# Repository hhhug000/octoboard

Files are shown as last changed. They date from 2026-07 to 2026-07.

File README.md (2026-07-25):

# Octoboard

An ATmega328P-PU development board designed from scratch in KiCad for prototyping AVR projects without breadboard mess. It uses only THT components to simplify soldering, and does not use an onboard serial chip to save on cost and simplicity

Octoboard breaks out all the GPIO from the chip, and provides all power management and supporting hardware.

The BOM is for 5 boards, as that is the minimum I can buy from JLCPCB and some parts

Built for the Hack Club Stardance YSWS program

---

## Visuals

### Renders

| Front | Back | Angle |
| ----  | ---- | ----- |
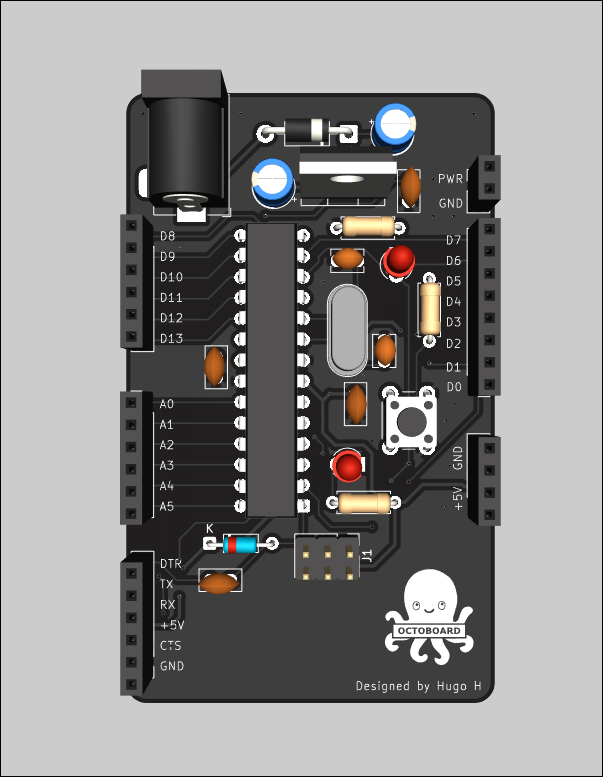
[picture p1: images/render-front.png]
Front
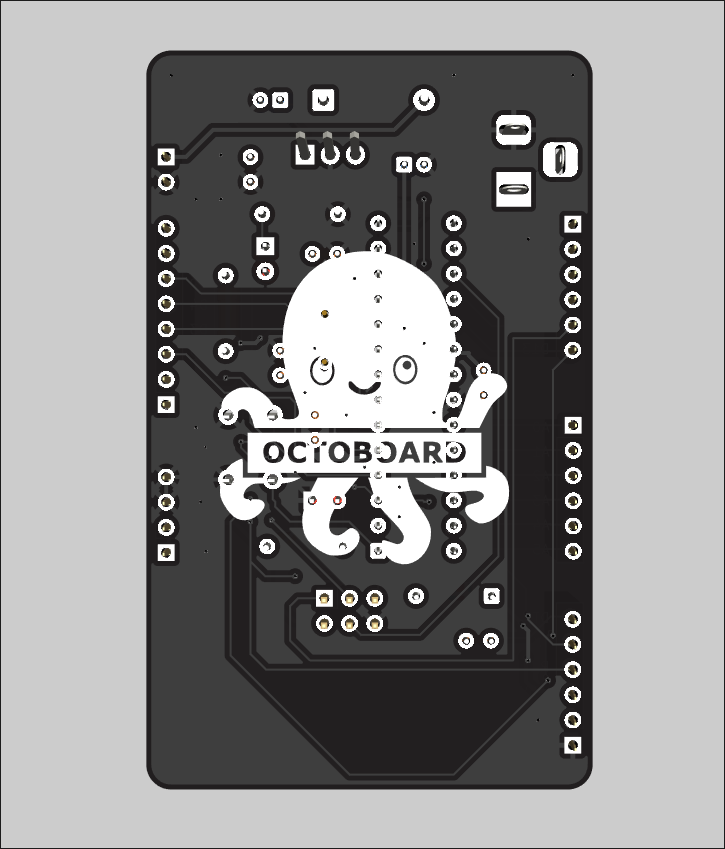
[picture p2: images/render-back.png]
Back
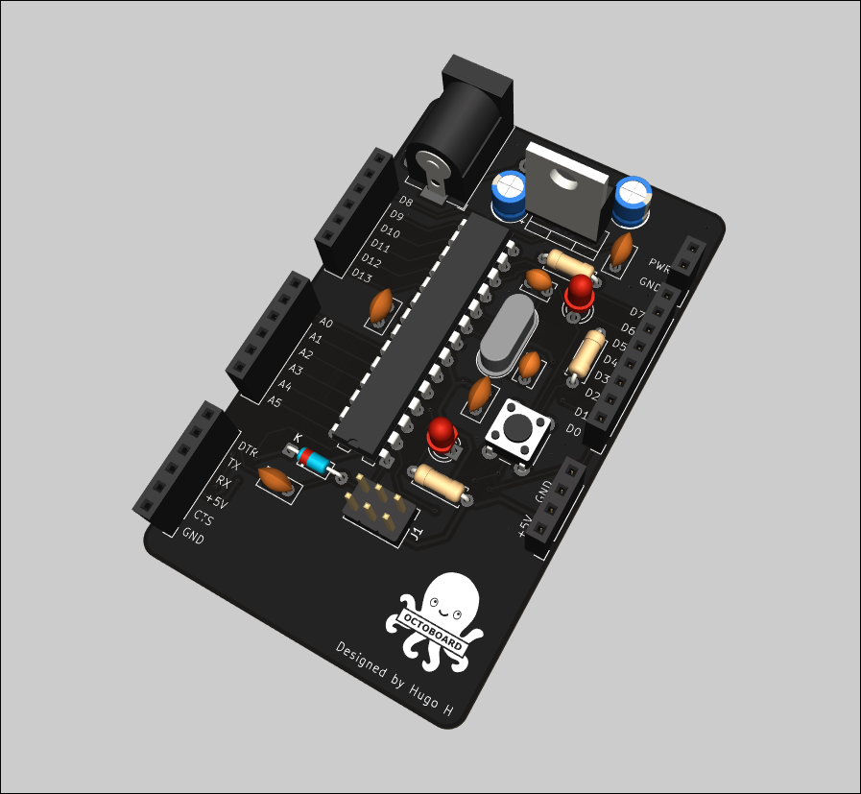
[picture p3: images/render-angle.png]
Angle
|  |  |  |

### PCB

| All Layers | Front Layer | Back Layer |
| --- | --- | --- |
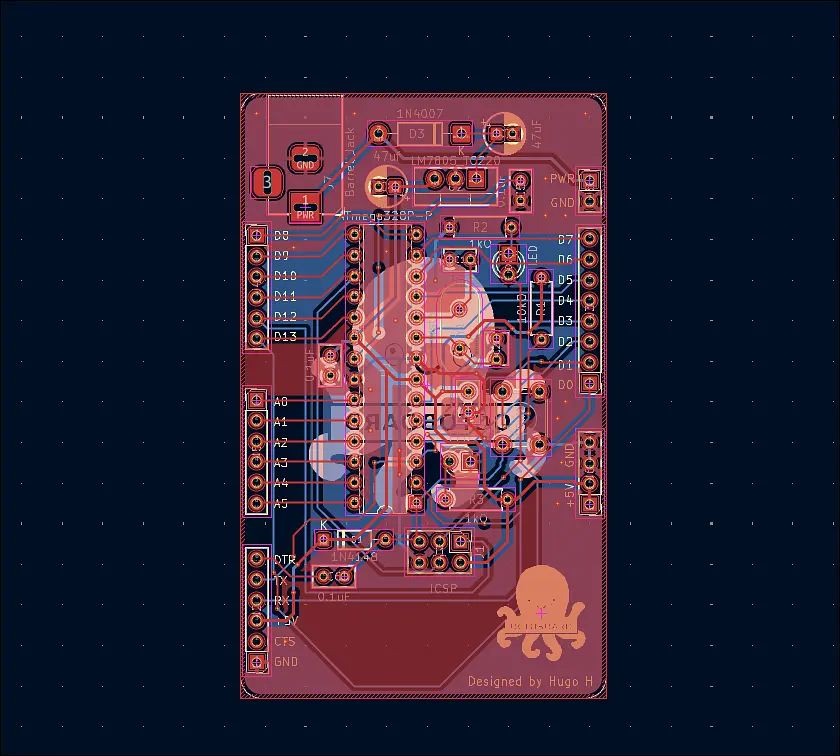
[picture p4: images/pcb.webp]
All Layers
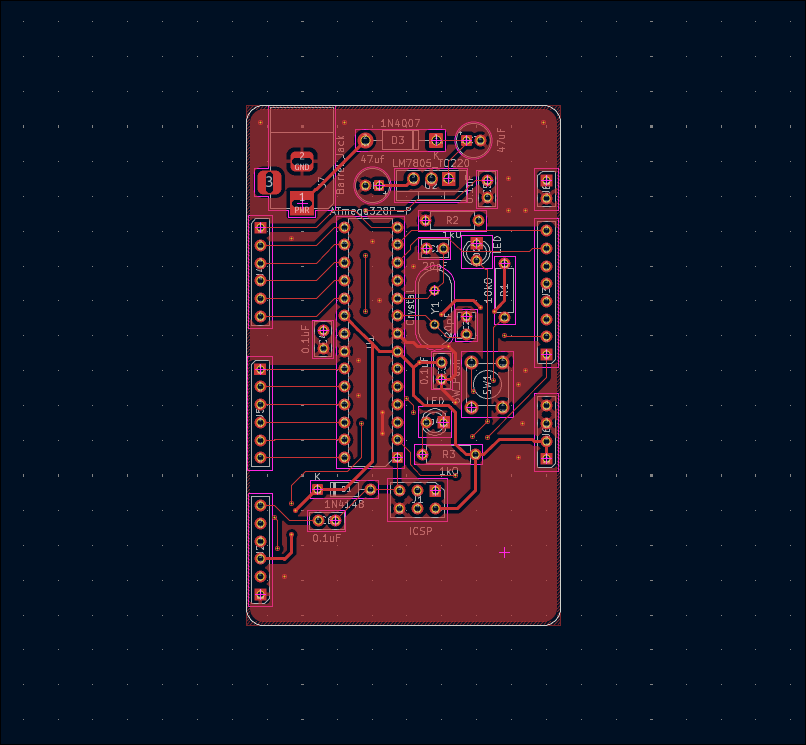
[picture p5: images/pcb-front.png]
Front Layer
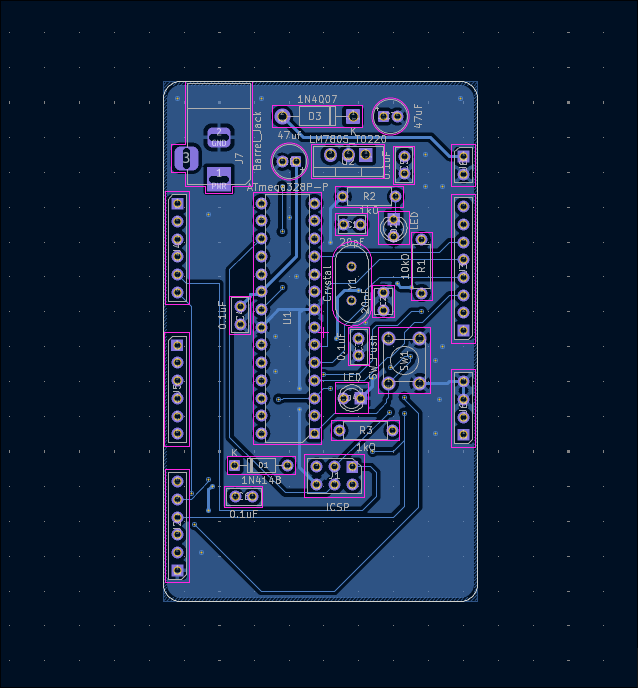
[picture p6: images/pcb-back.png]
Back Layer
|  |  |  |

### Explainer Video

OctoBoard Promo (http://www.youtube.com/watch?v=EGtcOqKRJP8 "Octoboard Promo")

---

## Design and Specs

*   **Microcontroller** ATmega328P-PU (DIP-28 package)
*   **Clock speed** External 16 MHz crystal oscillator
*   **I/O** All GPIO pins broken out to standardized 2.54mm pitch female headers
*   **Power management** Steps down barrel jack or input voltage to clean filtered 5v for the chip, and broken out for components
*   **Programming** Is programmed with standard Arduino C++, or any other lang with support like TinyGo or Micropython

---

## Notes

Make sure to flash the bootloader to the board in Arduino IDE even if you will only use ICSP.
This is because it programs the fuses, and programs will not work properly without it.

---

## Programming

The device can be programmed in a variety of languages.
I have personally tested it with Arduino C++ and my own blockly based system.
The device can be programmed with avrdude or the arduino ide.

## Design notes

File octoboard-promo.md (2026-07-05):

# Promo Material
Hello! This page has some promotional content for the Octoboard :)

## Explainer video

OctoBoard Promo (http://www.youtube.com/watch?v=EGtcOqKRJP8 "Octoboard Promo")

## PCBs
The KiCad design files are in this repo

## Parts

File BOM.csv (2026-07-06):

Part Name | Manufacturer | Price in GBP | Converted to USD (x1.33) | Quantity | Total Price in GBP | Converted to USD | CPC Farnell Order Code | Links | Notes
1N4007G+ Recovery Diode 1kV 1A, Single, 1V , 30A | MULTICOMP PRO | £0.03 | $0.04 | 10 | £0.30 | $0.40 | SC15525 | https://cpc.farnell.com/p/SC15525 | Min order quantity of 10
EEUFM1E470 Electrolytic Capacitor, 47uF, 25V, +/- 20% | PANASONIC | £0.23 | $0.31 | 10 | £2.30 | $3.06 | CA09929 | https://cpc.farnell.com/p/CA09929 | For power stuff
ATMEGA328P-PU MCU, 8Bit, AVR, 32K Flash 28PDIP | ATMEL | £2.85 | $3.79 | 5 | £14.25 | $18.95 | SC09742 | https://cpc.farnell.com/p/SC09742 | The main microcontroller chip!
AS-16.000-18 16MHz Crystal | RALTRON | £0.14 | $0.19 | 5 | £0.70 | $0.93 | SC18229 | https://cpc.farnell.com/p/SC18229 | Timing crystal
18688 Header, Female, Stackable, 2.54mm, 6 Way | PRO SIGNAL | £0.54 | $0.72 | 15 | £8.10 | $10.77 | CN18764 | https://cpc.farnell.com/p/CN18764 | GPIO Headers
M20-9990346 0.1" Pin Header, 3 Way, 10 Pack | HARWIN | £1.14 | $1.52 | 1 | £1.14 | $1.52 | CN09984 | https://cpc.farnell.com/p/CN09984 | Put 2 together for the 2x3 ICSP Header
HLMP-1340 LED, 3mm, HE-Red | BROADCOM | £0.17 | $0.23 | 10 | £1.70 | $2.26 | SC11554 | https://cpc.farnell.com/p/SC11554 | For power LED and programmable LED
1N4148 (DO-35) Small Signal Diode, 100Vm 150mA, 50 Pack | MULTICOMP PRO | £0.69 | $0.92 | 1 | £0.69 | $0.92 | SC07296 | https://cpc.farnell.com/p/SC07296 | For serial DTR
C320C104K5 R5TA Multilayer Ceramic Capacitor, 0.1uF 50V, +/- 10% Radial Leaded, 2.54mm | KEMET | £0.08 | $0.11 | 20 | £1.60 | $2.13 | CA09214 | https://cpc.farnell.com/p/CA09214 | For power stuff
K220J15C0G F53L2 Capacitor, 22pF, 50V, NP0, Radial | VISHAY | £0.08 | $0.11 | 10 | £0.80 | $1.06 | CA06803 | https://cpc.farnell.com/p/CA06803 | Crystal decoupling
FC68148 DC Power Socket, PCB Mount, DC 10A | CLIFF ELECTRONIC COMPONENTS | £0.44 | $0.59 | 5 | £2.20 | $2.93 | CN01545 | https://cpc.farnell.com/p/CN01545 | Power in barrel jack
L7805ABV Voltage Regulator 5v, 7805 | STMICROELECTRONICS | £0.34 | $0.45 | 5 | £1.70 | $2.26 | SC10586 | https://cpc.farnell.com/p/SC10586 | Voltage regulation
MF25 10K Resistor, 0.25W 1% 10K, 50 Pack | MULTICOMP PRO | £2.12 | $2.82 | 1 | £2.12 | $2.82 | RE03723 | https://cpc.farnell.com/p/RE03723 | Resists reset
MF25 1K Resistor, 0.25W 1% 1K, 50 Pack | MULTICOMP PRO | £1.38 | $1.84 | 1 | £1.38 | $1.84 | RE03722 | https://cpc.farnell.com/p/RE03722 | Resists for LEDs
PTS645SL50-2 LFS Tactile Switch SPST, 130gf, 12V DC, 50mA | C&K COMPONENTS | £0.17 | $0.23 | 5 | £0.85 | $1.13 | SW06710 | https://cpc.farnell.com/p/SW06710 | Reset switch
FIT0146 Stackable Female Header, 2.54mm, 8 Way, 10 Pack | DFROBOT | £2.59 | $3.44 | 2 | £5.18 | $6.89 | PC02802 | https://cpc.farnell.com/p/PC02802 | Can be cut and sanded for the other size headers
MC-2227-28-03-F1 IC Socket, DIL, 0.3" / 7.62mm, 28 Way, 17 Pack | MULTICOMP PRO | £2.47 | $3.29 | 1 | £2.47 | $3.29 | SC08129 | https://cpc.farnell.com/p/SC08129 | Holds microcontroller chip, so it is replacable
PCB, FR4, 2 Layers, Black Solder Mask, White Silkscreen (5 Pack + Shipping) | JLCPCB | £12.47 | $16.59 | 1 | £12.47 | $16.59 | N/A |  | The actual PCB
DollaTek USBASP USBISP AVR USBasp_H6 Programmer + 6 pin Cable | DollaTek (AMAZON) | £4.99 | $6.64 | 1 | £4.99 | $6.64 | N/A | https://www.amazon.co.uk/DollaTek-USBASP-USBasp_H6-Programmer-Support/dp/B07DK5M7LZ | To program the bootloader and direct program code
 |  |  |  |  | Total Price in GBP | £64.94
 |  |  |  |  | VAT (20%) | £12.99
 |  |  |  |  | Total Price in GBP with VAT | £77.93
 |  |  |  |  | Total Price in USD with VAT | £103.64

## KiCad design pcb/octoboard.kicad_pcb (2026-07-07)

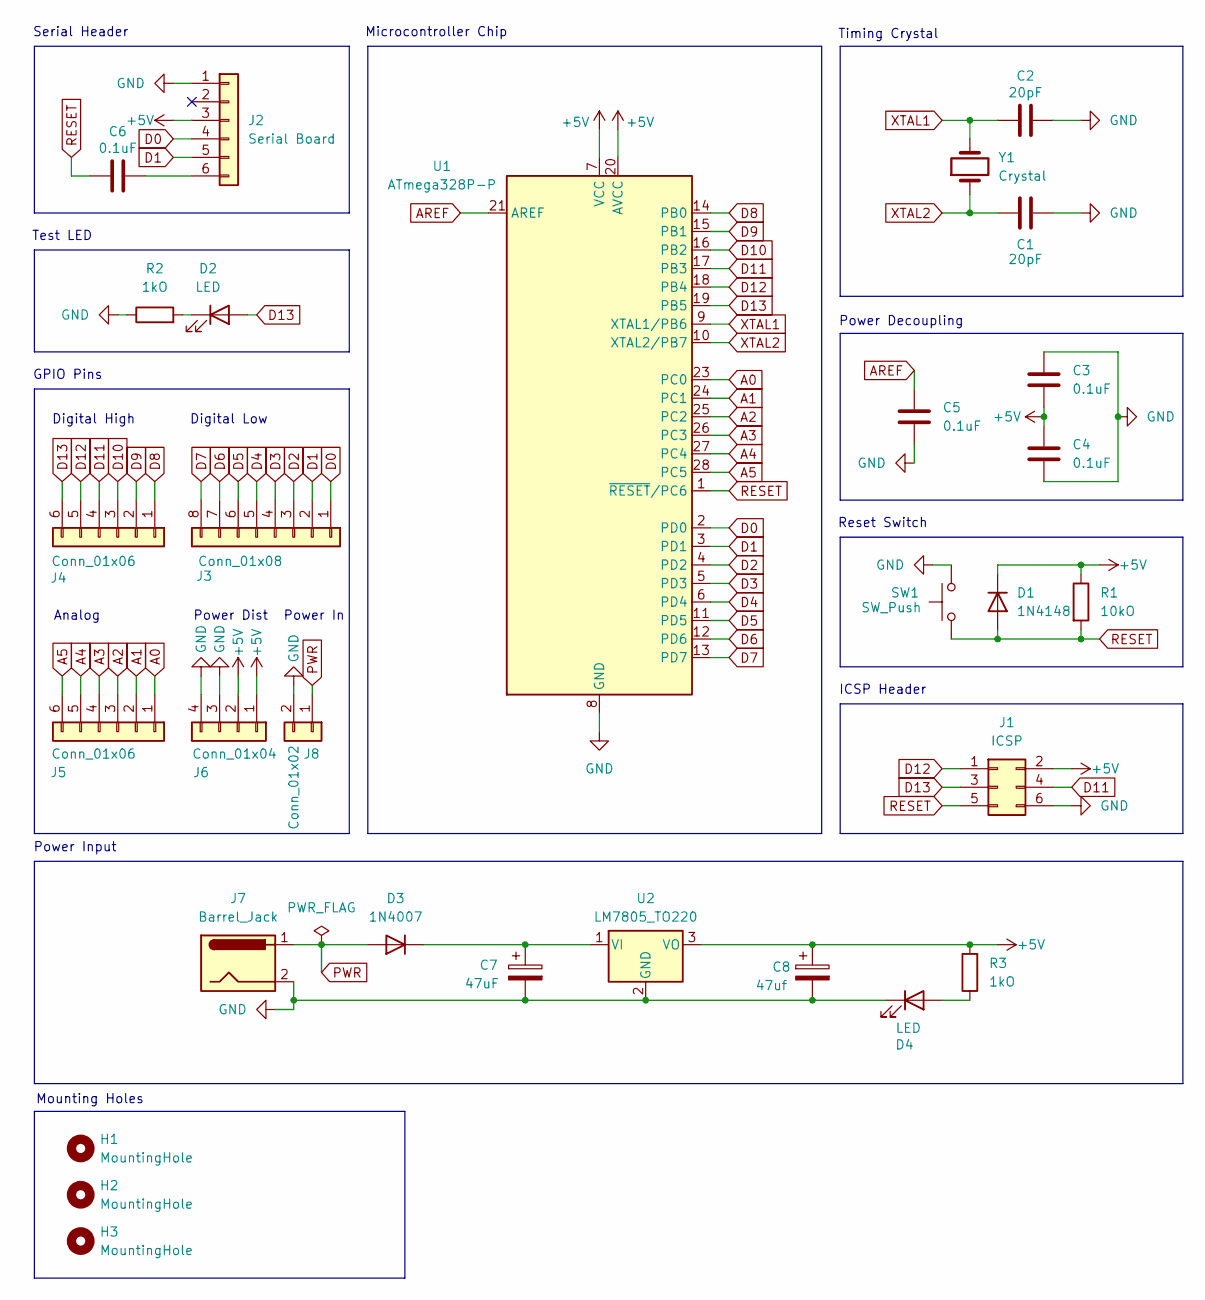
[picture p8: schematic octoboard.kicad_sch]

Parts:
C1, C2: 20pF; C_Disc_D3.8mm_W2.6mm_P2.50mm
C3, C4, C5, C6: 0.1uF; C_Disc_D5.0mm_W2.5mm_P2.50mm
C7: 47uF; CP_Radial_D5.0mm_P2.00mm
C8: 47uf; CP_Radial_D5.0mm_P2.00mm
D1: 1N4148; D_DO-35_SOD27_P7.62mm_Horizontal
D2, D4: LED; LED_D3.0mm
D3: 1N4007; D_DO-41_SOD81_P10.16mm_Horizontal
H1, H2, H3: MountingHole; MountingHole_2.2mm_M2
J1: ICSP; PinHeader_2x03_P2.54mm_Vertical
J2: Serial Board; PinHeader_1x06_P2.54mm_Vertical
J3: Conn_01x08; PinHeader_1x08_P2.54mm_Vertical
J4, J5: Conn_01x06; PinHeader_1x06_P2.54mm_Vertical
J6: Conn_01x04; PinHeader_1x04_P2.54mm_Vertical
J7: Barrel_Jack; BarrelJack_Horizontal
J8: Conn_01x02; PinHeader_1x02_P2.54mm_Vertical
R1: 10kO; R_Axial_DIN0207_L6.3mm_D2.5mm_P7.62mm_Horizontal
R2, R3: 1kO; R_Axial_DIN0207_L6.3mm_D2.5mm_P7.62mm_Horizontal
SW1: SW_Push; SW_PUSH_6mm
U1: ATmega328P-P; DIP-28_W7.62mm
U2: LM7805_TO220; TO-220-3_Vertical
Y1: Crystal; Crystal_HC49-4H_Vertical

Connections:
+5V: C3.2, C4.1, C8.1, D1.1 (K), J1.2, J2.3, J6.1, J6.2, R1.1, R3.2, U1.7 (VCC), U1.20 (AVCC), U2.3 (VO)
A0: J5.1, U1.23 (PC0)
A1: J5.2, U1.24 (PC1)
A2: J5.3, U1.25 (PC2)
A3: J5.4, U1.26 (PC3)
A4: J5.5, U1.27 (PC4)
A5: J5.6, U1.28 (PC5)
AREF: C5.1, U1.21 (AREF)
D0: J2.4, J3.1, U1.2 (PD0)
D1: J2.5, J3.2, U1.3 (PD1)
D2: J3.3, U1.4 (PD2)
D3: J3.4, U1.5 (PD3)
D4: J3.5, U1.6 (PD4)
D5: J3.6, U1.11 (PD5)
D6: J3.7, U1.12 (PD6)
D7: J3.8, U1.13 (PD7)
D8: J4.1, U1.14 (PB0)
D9: J4.2, U1.15 (PB1)
D10: J4.3, U1.16 (PB2)
D11: J1.4, J4.4, U1.17 (PB3)
D12: J1.1, J4.5, U1.18 (PB4)
D13: D2.2 (A), J1.3, J4.6, U1.19 (PB5)
GND: C1.1, C2.1, C3.1, C4.2, C5.2, C7.2, C8.2, D4.1 (K), J1.6, J2.1, J6.3, J6.4, J7.2, J8.2, R2.1, SW1.2, U1.8 (GND), U1.22 (GND), U2.2 (GND)
unnamed: D2.1 (K), R2.2
unnamed: C7.1, D3.1 (K), U2.1 (VI)
unnamed: D4.2 (A), R3.1
unnamed: C6.2, J2.6
PWR: D3.2 (A), J7.1, J8.1
RESET: C6.1, D1.2 (A), J1.5, R1.2, SW1.1, U1.1 (~RESET/PC6)
XTAL1: C2.2, U1.9 (XTAL1/PB6), Y1.2
XTAL2: C1.2, U1.10 (XTAL2/PB7), Y1.1

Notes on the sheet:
Serial Header
Power Input
Digital Low
Mounting Holes
Test LED
GPIO Pins
Power Dist
Timing Crystal
Power In
Microcontroller Chip
ICSP Header
Digital High
Analog
Reset Switch
Power Decoupling

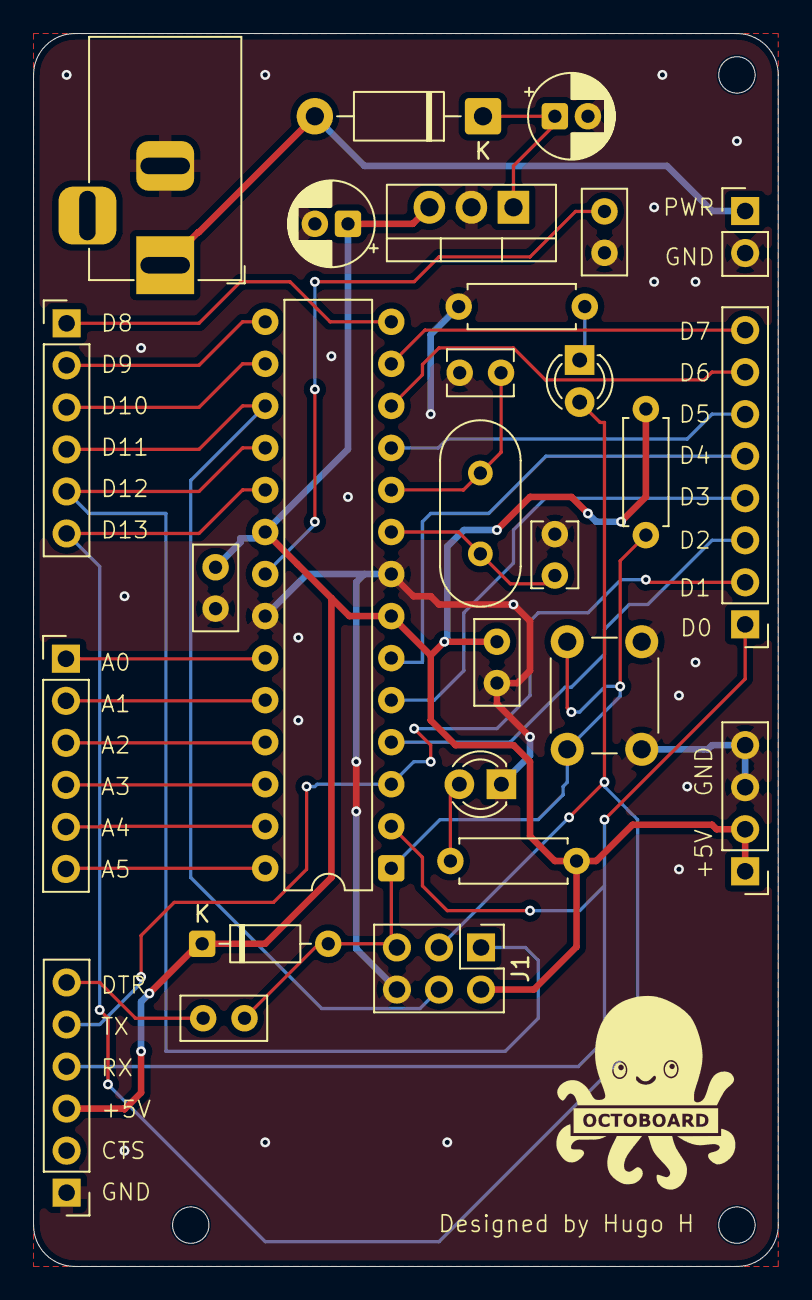
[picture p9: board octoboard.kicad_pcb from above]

Board: 2 copper layers, 45.0 x 74.5 mm, 30 parts (0 on the bottom side), 31 nets.

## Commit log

2026-07-03 added project
    [octoboard.kicad_pcb, octoboard.kicad_sch]
2026-07-05 Swapped out models to use PinSockets instead of PinHeaders (Except ICSP)
    [octoboard.kicad_pcb]
2026-07-05 Create octoboard-promo.md for promotional material
    Added promotional content and explainer video for Octoboard.
2026-07-06 Added more pcb images
2026-07-06 Added BOM
    [BOM.csv, BOM.xlsx]
2026-07-06 Exported to gerber
    [octoboard-B_Cu.gbr, octoboard-B_Mask.gbr, octoboard-B_Paste.gbr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]
2026-07-06 Updated folder structure
    [octoboard-B_Cu.gbr, octoboard-B_Mask.gbr, octoboard-B_Paste.gbr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]
2026-07-06 Added links col to bom
    [BOM.csv, BOM.xlsx]
2026-07-07 Added some mounting holes
    how tf did i forget that
    [octoboard.kicad_pcb, octoboard.kicad_sch]
2026-07-07 updated exported gerbers
    [octoboard-B_Cu.gbr, octoboard-B_Mask.gbr, octoboard-B_Paste.gbr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]
